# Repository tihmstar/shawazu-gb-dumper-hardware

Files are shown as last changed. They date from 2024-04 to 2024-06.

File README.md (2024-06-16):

# Shawazu GB Dumper Hardware
Custom Shawazu PCB for dumping GB / GBC / GBA games and savegames.  
This is an easy to solder DIY project.

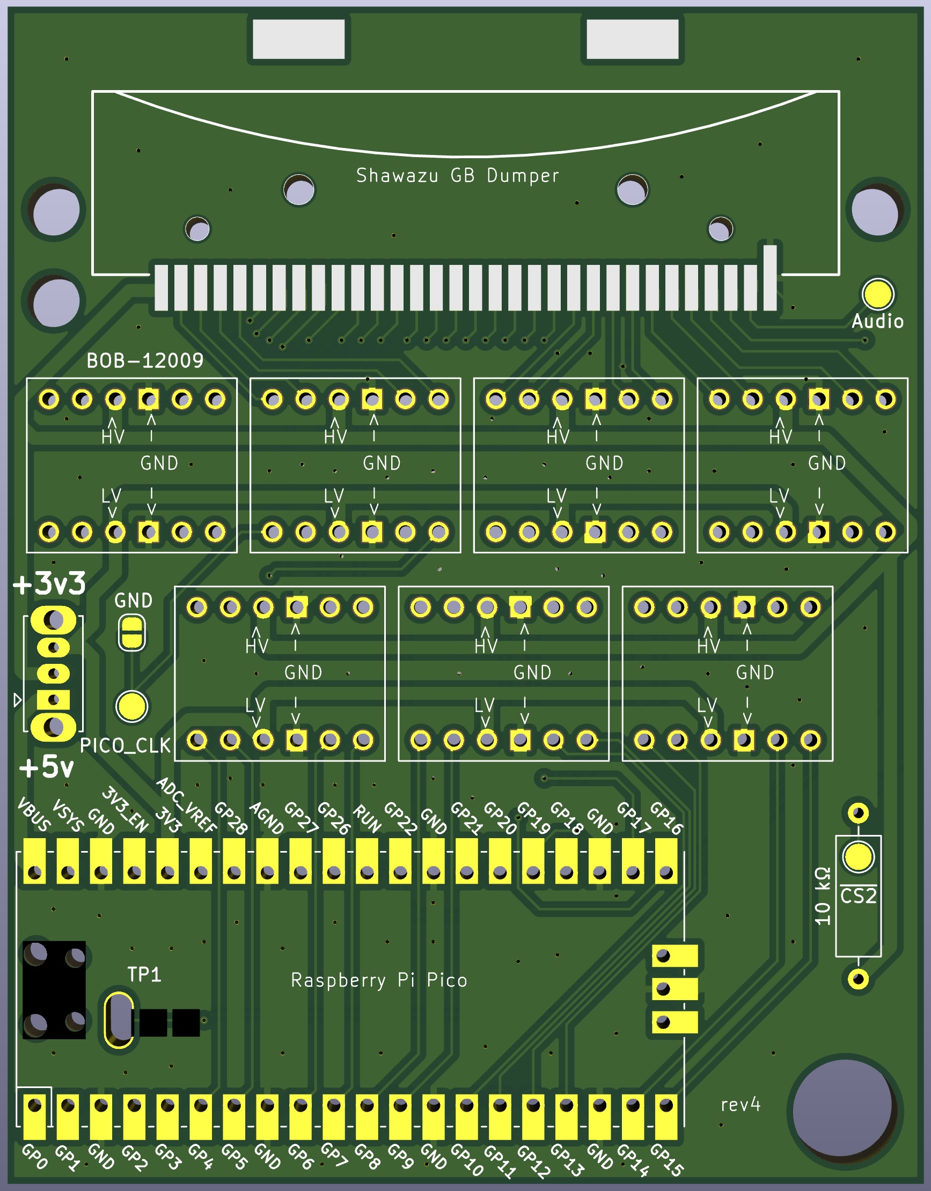
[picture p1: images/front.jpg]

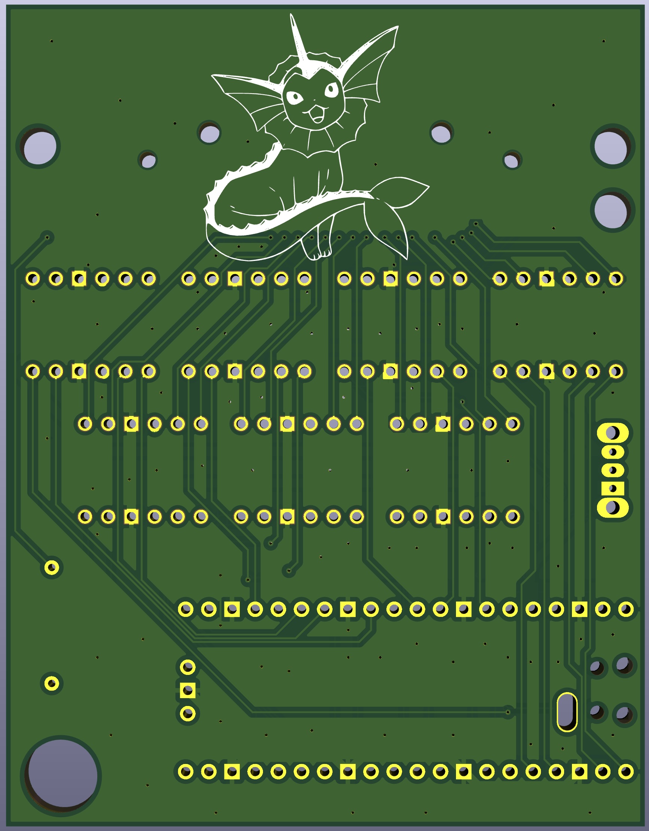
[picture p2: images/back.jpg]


# 3D printed case
A 3d printed case is available for rev 3 / rev 4 boards [here](https://github.com/tihmstar/shawazu-gb-dumper-hardware/tree/master/case).  
**Note: The case does not fit rev2 boards!**

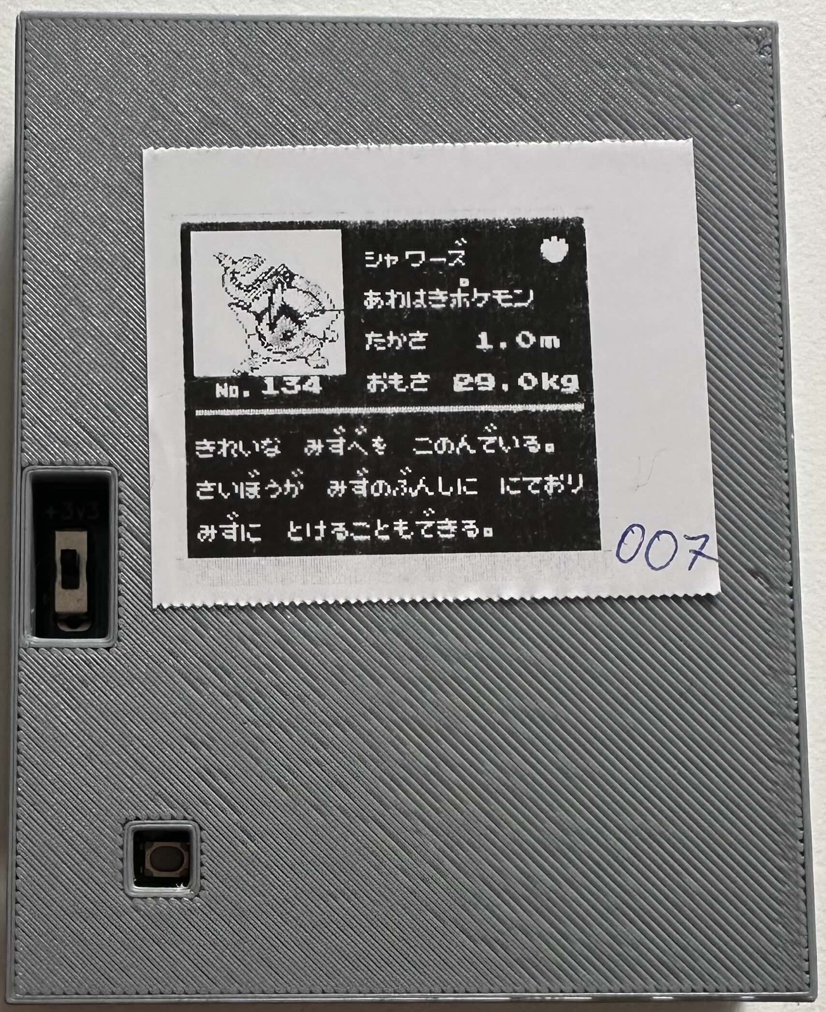
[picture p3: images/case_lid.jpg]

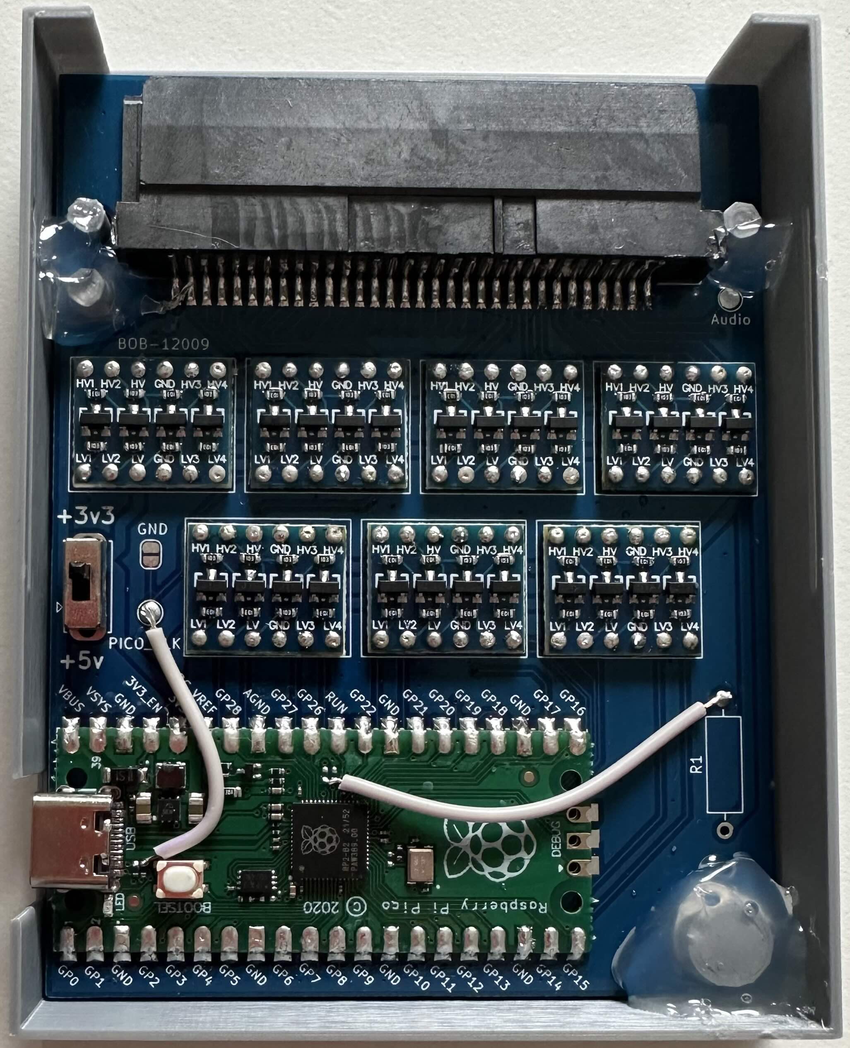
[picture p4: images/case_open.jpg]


# Voltage switch 
GB / GBC cartridges run on 5V.  
GBA cartridges run on 3.3V.  

Always set the correct voltage **before** plugging in the cartridge!

# Bill Of Materials
* 1 x Raspberry Pi Pico
* 7 x BOB-12009 (4 bit level shifter)
* 1 x Switch (3 pin 2 position panel, 3mm)
* 1 x 32pin Gameboy Cartridge Connector
* 2 x wires

It is important that the pico has the footprint of an original pico. It is possible to use cheap USB-C picos from china but original is recommended.  
The project uses GPIO23 as a bidirectional data pin, which on a raspberry pi pico is connected to the on-board SMPS Power Save pin. While doing this is kinda out of spec, it works fine in practise. However, on some cheap USB-C picos from china it can cause bootloops and thus may be problematic. It worked fine for me most of the time, but a few picos had the bootloop issue.

The switches i used are https://www.amazon.de/gp/product/B09TVFF6KW. They fit like 95%. Just a little squeezing is needed.  

For the connector, just pick one from AliExpress. They should be pretty much all the same, so any that looks like it fits should work.

# Assembly

A video tutorial on how to assembly the board is available here:  
Buildinstructions (https://www.youtube.com/watch?v=dES8QW8xg44)

In General:  
1) **Flash and test the pico!!!!!**
2) Solder the 7 level shifter
3) Solder the connector
4) Solder the switch
5) Solder the pico (front side only)
6) **Test the pico again!!!**
7) Solder to the pico testpoint through the whole in the back of the PCB
8) **Test the pico again!!!**
9) Optional 1: Solder the TP near the switch on the PCB to the LED of the Pico (check video)
10) **Test the pico again!!!**
11) Optional 2: (check video)
- Remove the two resistors on the pico
- **Test the pico again!!!**
- Solder the upper pad of the resistor placeholder on the PCB to the correct pad where you removed the resistors on the pico (check video)
12) Finally: test the finished assembly

**Make sure to test the pico over and over during assembly! Otherwise it will be extremely difficult to debug what is wrong in case the final thing doesn't _just work_!!!!**  

### "Testing the pico"
Flash the [Shawazu firmware](https://github.com/tihmstar/shawazu-gb-dumper) to your pico and make sure a drive called _SHAWAZU_ appears when you plug it in. The drive should contain one file _Info.txt_ which says that no cartridge is connected. After the relevant assembly steps connect the pico again and check if the drive with the file still shows up.  
If the drive doesn't show up before assembly and you realize the pico is dead, do no solder it on the PCB.  
**Once soldered to the PCB it is ~~impossible~~ extremely diffucult to remove the pico without damaging anything!!!**  
If the drive showed up before assembly but does no longer show up after a certain step, go back and debug/fix your previous assembly step. If you don't test the pico after every modification it will be very hard to tell which step exactly causes the failure!

# Optional solders
There are 2 so called "optional solders" on the board. You will need to solder both correctly if you want to have all features of shawazu. Let's take a look at what each of them do

## Optional solder 1
This solder point refers to the testpoint which is closer to the power switch on the PCB. The TP needs to be soldered to GPIO25, which is used by the LED. The LED seems not to interfere and can be left on the board.  
There are multiple revisions of the PCB with different pinout.

### Optional solder: PICO_<span style="text-decoration:overline">CS</span>
**You pretty much always want to solder this!**

The negated chipselect line is set low (enabled) when talking to GB / GBC ROM and set high (disabled) when talking to GB / GBC SRAM. Some cartridges (especially those without savestate) may ignore this so those can be talked to without this. It is possible to enable the solderbridge to ground this pin to always have the ROM enabled, but this may cause issues in some GB / GBC games.

On GBA games this line is used to "clock" the bus for transfer to ROM (and flash/eeprom savestate).   
**Without this line GBA cartridges will not work**.

### Optional solder: PICO_CLK
**Needed for Gameboy Camera. Other Cartridges may work without this**  

The gameboy CLK line is rarely used by any GB / GBC cartridge. The only cartridge i have tested that actually needs this line is the Gameboy Camera. If you don't plan on using the Gameboy Camera it is fine to leave this alone. Do NOT ground this line with the solderbridge.

As far as i'm aware, GBA does not use the CLK.

## Optional solder 2
This solder point refers the the upper pad of the resistor placeholder. Rev 4 has a dedicated TP on on the PCB labled as "<span style="text-decoration:overline">CS2</span>", which is connected to the upper pad of the resistor placeholder. Earlier revisions do not have a dedicated TP, there you just solder to the upper resistor placeholder. 
This point should be connected to GPIO24 on the pico. That GPIO is normally used to detect whether 5V (eg via USB) is available, or if the pico is powered by 3.3V. To use the GPIO is is **required** to remove 2 resistors.   
**Without removing the two resistors you cannot use the GPIO!!!!** 

### Optional solder: <span style="text-decoration:overline">CS2</span>
**Solder for GBA savegame support. If you don't care about GBA, place a 10k resistor on the PCB**

On GB / GBC cartridges this pin is called _<span style="text-decoration:overline">RST</span>_ and used to reset the Gameboy CPU from the cartridge. Most cartridges do not care about this pin, but some (Gameboy Camera) want this to be pulled high.

On GBA this pin is called <span style="text-decoration:overline">CS2</span> and is used to "clock" the SRAM. Without this pin SRAM is not accessible and thus savegame of some GBA cartridges cannot be read / written. Some cartridges which use EEPROM / Flash based savegame may not need this pin, but if you plan to use GBA cartridges it is recommended to solder this.

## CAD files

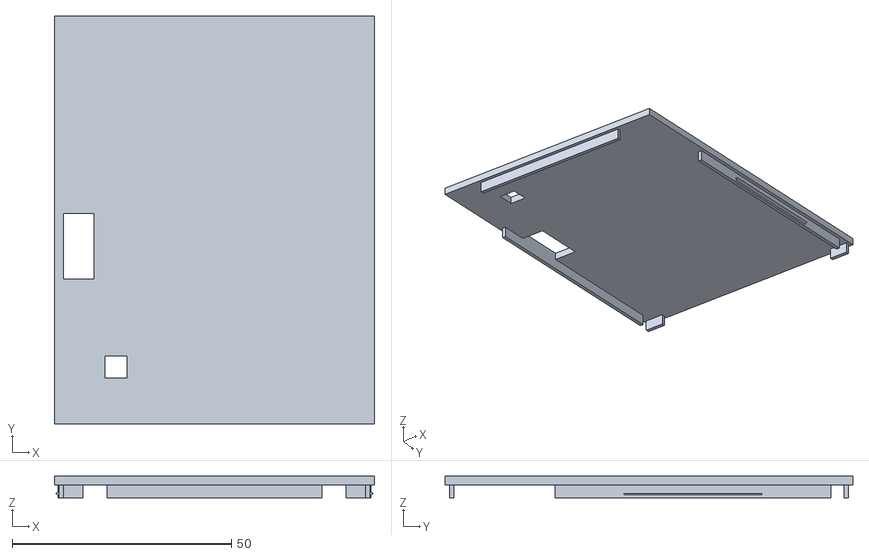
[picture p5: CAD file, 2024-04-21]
case/case_v4_top.stl
73.0 x 93.0 x 5.00

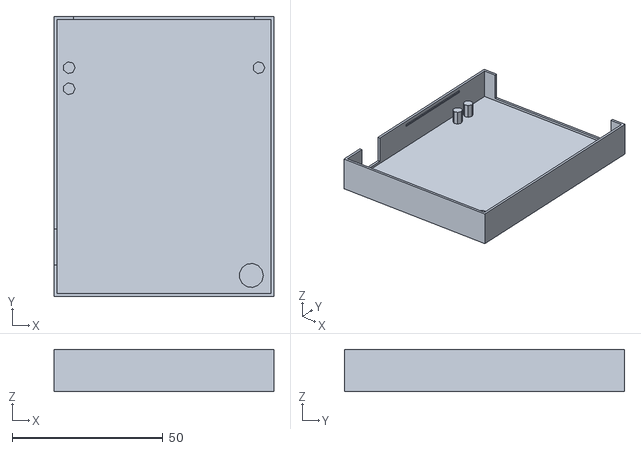
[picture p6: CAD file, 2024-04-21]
case/case_v4_bottom.stl
73.0 x 93.0 x 14.0

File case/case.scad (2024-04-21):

board_height = 90;
board_width  = 70;
case_border = 1.5;
pin_height = 6;

case_height = 14;
cart_wall_corners = 5;
usb_cutout_width = 12;


top_walls = 3;
top_wall_factor = 0.70;
top_side_wall_offset = 10;

indent_factor = 0.5;

module bottom(x = 0, y = 0, z = 0){
    pin_radius_small = 2;
    pin_radius_large = 4;
    
    translate([x-(board_width+case_border*2)/2,y-(board_height+case_border*2)/2,z]){
        cube([board_width+case_border*2,board_height+case_border*2,2]);
        color("blue"){
            translate([case_border,case_border])
                cube([board_width,board_height,2]);
        }
        color("red"){
            translate([3.5+case_border,case_border+board_height-15.5-7,0]){
                cylinder(pin_height+case_border, pin_radius_small, pin_radius_small);
            }

            translate([3.5+case_border,case_border+board_height-15.5,0]){
                cylinder(pin_height+case_border, pin_radius_small, pin_radius_small);
            }
            translate([case_border+board_width-3.5,case_border+board_height-15.5,0]){
                cylinder(pin_height+case_border, pin_radius_small, pin_radius_small);
            }


            translate([case_border+board_width-6,case_border+5.5,0]){
                cylinder(pin_height+case_border, pin_radius_large, pin_radius_large);
            }
        }
        
        /*
            Sidewalls
        */
        translate([0,0,0]){
            difference(){
                cube([1,board_height+case_border*2,case_height]); //left
                
                translate([-1,case_border+9,case_border*2]){
                    cube([3,usb_cutout_width,8+10]);
                }


                translate([0.5,indent_pos,case_height-top_walls+1/2])
                    cube([1.5,board_height*top_wall_factor*indent_factor+4,1]);
            }
        }
        
        indent_pos = case_border+(board_height*(1-top_wall_factor)/2)+top_side_wall_offset + 15;
    
        translate([board_width+case_border*2-1,0,0]){
            difference(){
                cube([1,board_height+case_border*2,case_height]); //right
                
                translate([-1,indent_pos,case_height-top_walls+1/2])
                    cube([1.5,board_height*top_wall_factor*indent_factor+4,1]);
            }
        }


        translate([0,0,0])
            cube([board_width+case_border*2,1,case_height]); //bottom

        translate([0,case_border*2+board_height-1,0]){
            difference(){
                cube([board_width+case_border*2,1,case_height]); //top
                
                
                translate([case_border+cart_wall_corners,-1,case_border*2]){
                    cube([board_width-cart_wall_corners*2,3,case_height]);
                }
            }
        }
    }
}


module top(x = 0, y = 0, z = 0){
    switch_cutout_width = 7;
    switch_cutout_height = 15;

    translate([x-(board_width+case_border*2)/2,y-(board_height+case_border*2)/2,z+case_height]){
        difference(){
            color("purple")
            cube([board_width+case_border*2,board_height+case_border*2,2]);

            //power selector
            translate([case_border+0.5,case_border+37-switch_cutout_height/2+2,-5])
                cube([switch_cutout_width,switch_cutout_height,10]);
            
            //bootsel
            translate([case_border+10,case_border+9,-5]){
                cube([5,5,10]);                
            }
        }

        
        /*
            Sidewalls
        */
        translate([1,case_border+(board_height*(1-top_wall_factor)/2)+top_side_wall_offset,-top_walls]){
            color("green")
            cube([1,board_height*top_wall_factor,case_border+top_walls]); //left                
            translate([0.25,board_height*top_wall_factor-(1-indent_factor)*board_height*top_wall_factor/2,1]){
                rotate([0,180,0])
                rotate([90,0,0])
                color("blue")
                cylinder(board_height*top_wall_factor*indent_factor,1,1,$fn=3);
            }
        }

        translate([board_width+case_border-0.5,case_border+(board_height*(1-top_wall_factor)/2)+top_side_wall_offset,-top_walls]){
            color("green")
            cube([1,board_height*top_wall_factor,case_border+top_walls]); //right
            translate([0.75,board_height*top_wall_factor-(1-indent_factor)*board_height*top_wall_factor/2,1]){
                rotate([90,0,0])
                color("blue")
                cylinder(board_height*top_wall_factor*indent_factor,1,1,$fn=3);
            }
        }

        color("grey")
        translate([case_border+(board_width*(1-top_wall_factor))/2,1,-top_walls])
            cube([board_width*top_wall_factor,1,case_border+top_walls]); //bottom

        color("grey")
        translate([case_border/2,board_height+case_border-0.5,-top_walls]){
            difference(){
                cube([board_width+case_border,1,case_border+top_walls]); //top
                
                translate([case_border/2+cart_wall_corners,-1,-1])
                    cube([board_width-cart_wall_corners*2,3,case_border+top_walls+3]);
            }
        }
    }
}




bottom(0,0,0);
top(0,0,0);

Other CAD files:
case/case_v3.scad

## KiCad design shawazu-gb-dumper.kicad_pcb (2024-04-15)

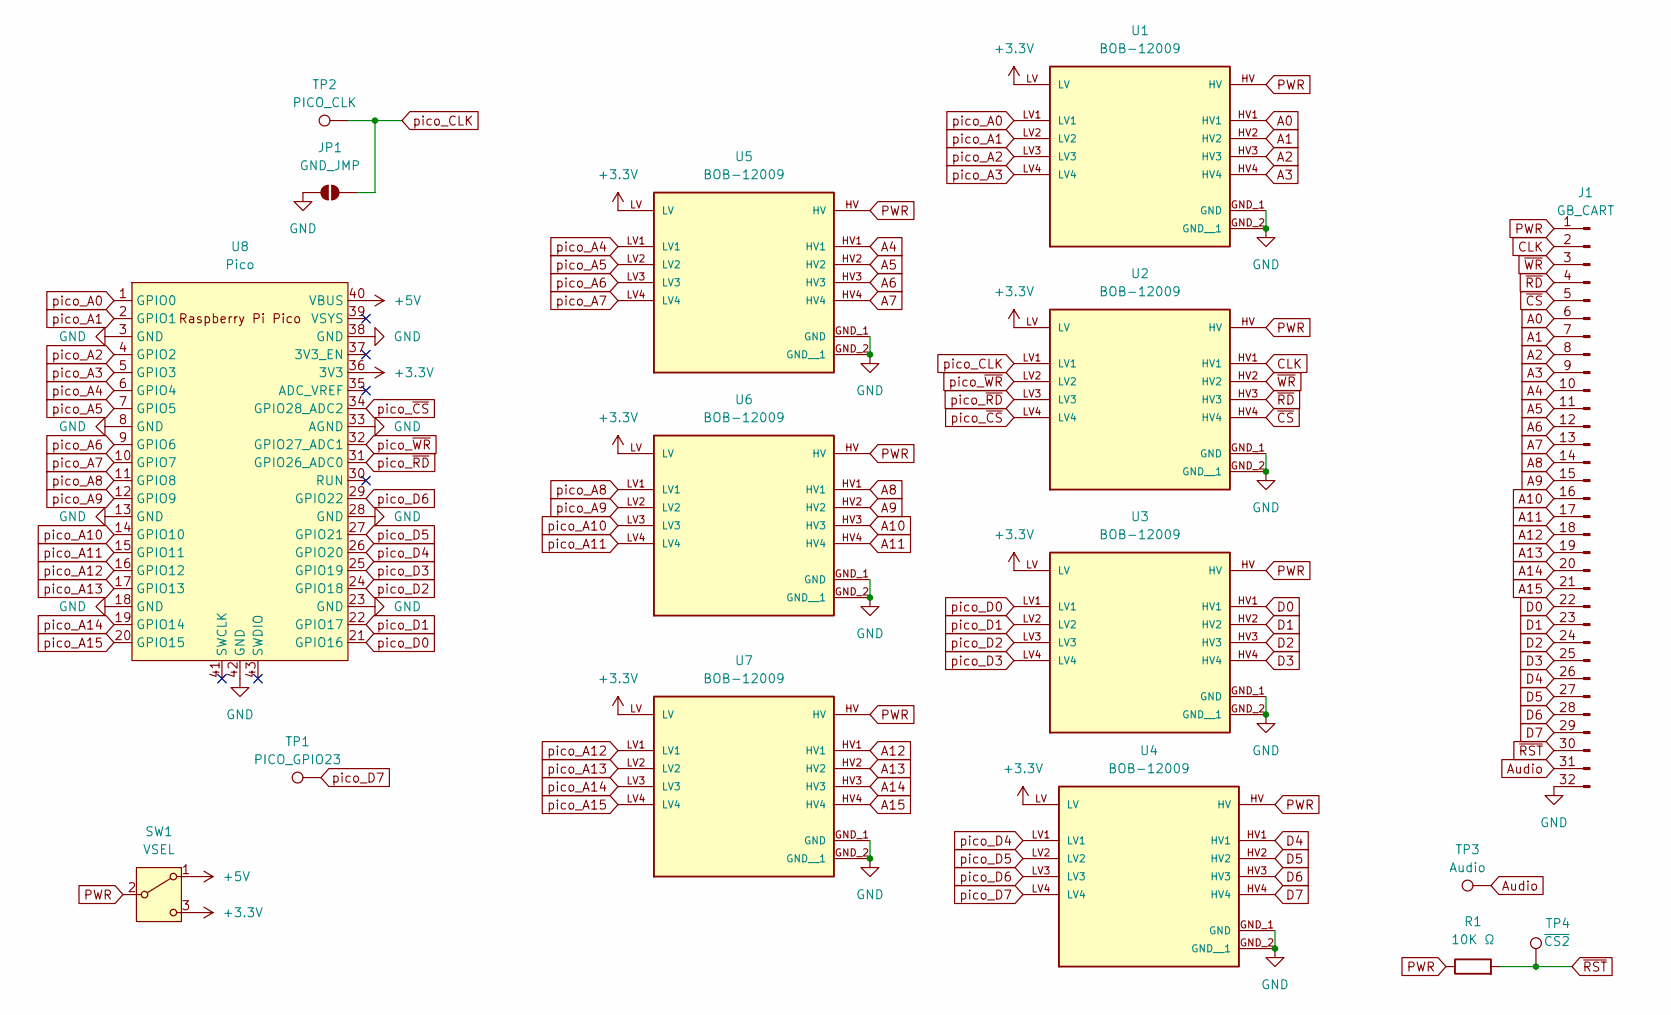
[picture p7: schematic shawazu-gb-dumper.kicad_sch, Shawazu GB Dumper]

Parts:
J1: GB_CART; GB_CART_4holes
JP1: GND_JMP; SolderJumper-2_P1.3mm_Open_RoundedPad1.0x1.5mm
R1: 10K Ω; R_Axial_DIN0309_L9.0mm_D3.2mm_P12.70mm_Horizontal
SW1: VSEL; SW_Slide_SPDT_Straight_CK_OS102011MS2Q
TP1: PICO_GPIO23; TestPoint_Plated_Hole_D4.0mm
TP2: PICO_CLK; TestPoint_Pad_D2.0mm
TP3: Audio; TestPoint_Pad_D2.0mm
TP4: ~{CS2}; TestPoint_Pad_D2.0mm
U1, U2, U3, U4, U5, U6, U7: BOB-12009; CONV_BOB-12009; PARTREV 01
U8: Pico; RPi_Pico_SMD_TH

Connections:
+3.3V: SW1.3 (C), U1.LV, U2.LV, U3.LV, U4.LV, U5.LV, U6.LV, U7.LV, U8.36 (3V3)
+5V: SW1.1 (A), U8.40 (VBUS)
A0: J1.6, U1.HV1
A1: J1.7, U1.HV2
A2: J1.8, U1.HV3
A3: J1.9, U1.HV4
A4: J1.10, U5.HV1
A5: J1.11, U5.HV2
A6: J1.12, U5.HV3
A7: J1.13, U5.HV4
A8: J1.14, U6.HV1
A9: J1.15, U6.HV2
A10: J1.16, U6.HV3
A11: J1.17, U6.HV4
A12: J1.18, U7.HV1
A13: J1.19, U7.HV2
A14: J1.20, U7.HV3
A15: J1.21, U7.HV4
Audio: J1.31, TP3.1
CLK: J1.2, U2.HV1
D0: J1.22, U3.HV1
D1: J1.23, U3.HV2
D2: J1.24, U3.HV3
D3: J1.25, U3.HV4
D4: J1.26, U4.HV1
D5: J1.27, U4.HV2
D6: J1.28, U4.HV3
D7: J1.29, U4.HV4
GND: J1.32, JP1.1 (A), U1.GND_1 (GND), U1.GND_2 (GND__1), U2.GND_1 (GND), U2.GND_2 (GND__1), U3.GND_1 (GND), U3.GND_2 (GND__1), U4.GND_1 (GND), U4.GND_2 (GND__1), U5.GND_1 (GND), U5.GND_2 (GND__1), U6.GND_1 (GND), U6.GND_2 (GND__1), U7.GND_1 (GND), U7.GND_2 (GND__1), U8.3 (GND), U8.8 (GND), U8.13 (GND), U8.18 (GND), U8.23 (GND), U8.28 (GND), U8.33 (AGND), U8.38 (GND), U8.42 (GND)
PWR: J1.1, R1.1, SW1.2 (B), U1.HV, U2.HV, U3.HV, U4.HV, U5.HV, U6.HV, U7.HV; also elsewhere on the board
pico_A0: U1.LV1, U8.1 (GPIO0)
pico_A1: U1.LV2, U8.2 (GPIO1)
pico_A2: U1.LV3, U8.4 (GPIO2)
pico_A3: U1.LV4, U8.5 (GPIO3)
pico_A4: U5.LV1, U8.6 (GPIO4)
pico_A5: U5.LV2, U8.7 (GPIO5)
pico_A6: U5.LV3, U8.9 (GPIO6)
pico_A7: U5.LV4, U8.10 (GPIO7)
pico_A8: U6.LV1, U8.11 (GPIO8)
pico_A9: U6.LV2, U8.12 (GPIO9)
pico_A10: U6.LV3, U8.14 (GPIO10)
pico_A11: U6.LV4, U8.15 (GPIO11)
pico_A12: U7.LV1, U8.16 (GPIO12)
pico_A13: U7.LV2, U8.17 (GPIO13)
pico_A14: U7.LV3, U8.19 (GPIO14)
pico_A15: U7.LV4, U8.20 (GPIO15)
pico_CLK: JP1.2 (B), TP2.1, U2.LV1
pico_D0: U3.LV1, U8.21 (GPIO16)
pico_D1: U3.LV2, U8.22 (GPIO17)
pico_D2: U3.LV3, U8.24 (GPIO18)
pico_D3: U3.LV4, U8.25 (GPIO19)
pico_D4: U4.LV1, U8.26 (GPIO20)
pico_D5: U4.LV2, U8.27 (GPIO21)
pico_D6: U4.LV3, U8.29 (GPIO22)
pico_D7: TP1.1, U4.LV4
pico_~CS: U2.LV4, U8.34 (GPIO28_ADC2)
pico_~RD: U2.LV3, U8.31 (GPIO26_ADC0)
pico_~WR: U2.LV2, U8.32 (GPIO27_ADC1)
~CS: J1.5, U2.HV4
~RD: J1.4, U2.HV3
~RST: J1.30, R1.2, TP4.1; also elsewhere on the board
~WR: J1.3, U2.HV2

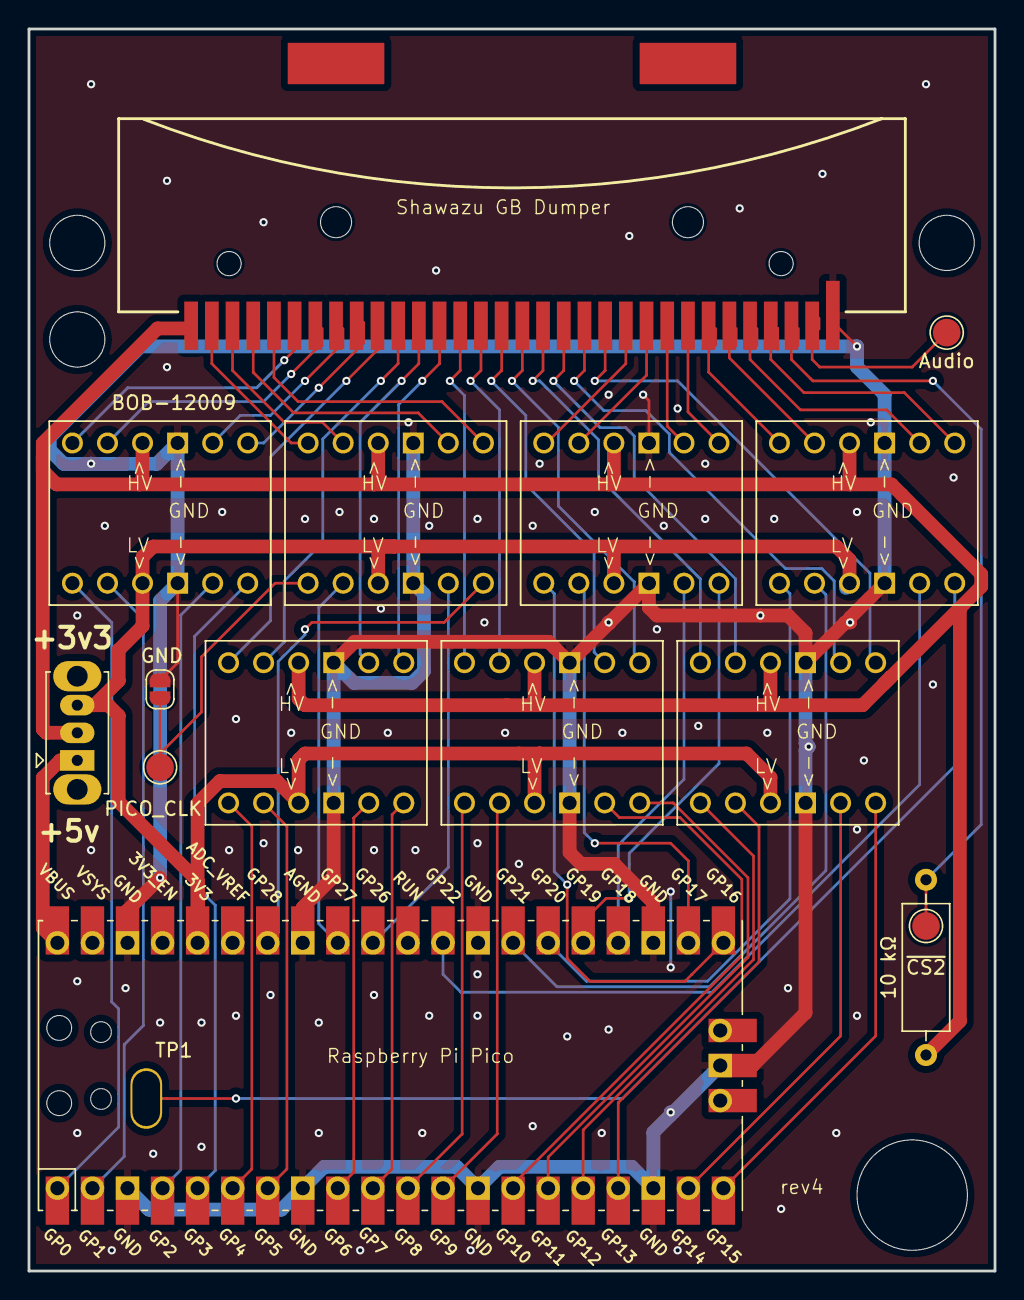
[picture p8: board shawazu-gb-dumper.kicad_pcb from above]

Board: 2 copper layers, 70.0 x 90.0 mm, 16 parts (0 on the bottom side), 62 nets.

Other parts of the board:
10 kΩ: 10K Ω; R_Axial_DIN0309_L9.0mm_D3.2mm_P12.70mm_Horizontal

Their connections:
PWR: 10 kΩ.1; also elsewhere on the board
~RST: 10 kΩ.2; also elsewhere on the board

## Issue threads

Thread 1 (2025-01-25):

How do I flash the PI pico?

paintrally, 2025-01-25:
I am love this project and am looking to make this project! How do you flash the pi pico? In the guide it says how to update it _"Updating
Drag and drop the .uf2 file to SHAWAZU drive will cause the rp2040 to enter bootloader (update) mode. When in bootloader more, drag and drop the .uf2 to the RPI-RP2 drive."_ but it never says how to flash it for the first time. Thank you so much!

I also have just one more thing, how do I send the gerber/s to a pcb manufacturer?

tihmstar, 2025-02-13:
For initial flashing, manually put the pico in Bootloader mode, then drag and drop the UF2 file to the RPI-RP2 drive.

Closed 2025-02-13.

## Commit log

2024-03-28 new hardware design
    [shawazu-gb-dumper-B_Cu.gbr, shawazu-gb-dumper-B_Mask.gbr, shawazu-gb-dumper-B_Paste.gbr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]
2024-03-29 Fell for: Trap for young players
    [shawazu-gb-dumper-B_Cu.gbr, shawazu-gb-dumper-B_Mask.gbr, shawazu-gb-dumper-B_Paste.gbr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]
2024-04-02 switched TP nCS with CLK
    [shawazu-gb-dumper.kicad_pcb, shawazu-gb-dumper.kicad_sch]
2024-04-02 removed from gnd plate
    [shawazu-gb-dumper.kicad_pcb]
2024-04-02 improve gnd
    [shawazu-gb-dumper.kicad_pcb]
2024-04-03 move repos
    [shawazu-gb-dumper-B_Cu.gbr, shawazu-gb-dumper-B_Mask.gbr, shawazu-gb-dumper-B_Paste.gbr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]
2024-04-03 new PCB release
    [shawazu-gb-dumper-B_Cu.gbr, shawazu-gb-dumper-B_Mask.gbr, shawazu-gb-dumper-B_Paste.gbr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]
2024-04-03 pcb v2 (actually)
    [shawazu-gb-dumper-B_Cu.gbr, shawazu-gb-dumper-B_Mask.gbr, shawazu-gb-dumper-B_Paste.gbr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]
2024-04-03 add more vias because vias are free (this on i actually ordered)
    [shawazu-gb-dumper-B_Cu.gbr, shawazu-gb-dumper-B_Mask.gbr, shawazu-gb-dumper-B_Paste.gbr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]
2024-04-21 add 3D printable case (for rev3/rev4 boards)
    [case.scad, case_v3.scad, case_v3_bottom.stl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]
2024-04-21 case v4
    [case.scad, case_v3_bottom.stl, case_v3_top.stl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]
2024-06-16 add 3d case images
